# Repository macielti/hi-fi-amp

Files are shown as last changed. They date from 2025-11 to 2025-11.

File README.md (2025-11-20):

# Hi-Fi Audio Amplifier project

Class A audio amplifier project based on JLH 1969 project.

Lista de componentes com valores aproximados: [Lista de Componentes Eletrônicos](https://github.com/macielti/hi-fi-amp/blob/main/docs/Lista%20de%20Componentes%20Eletrônicos.md)

## Exemplo da placa Fonte de Alimentação montada

<p align="center">
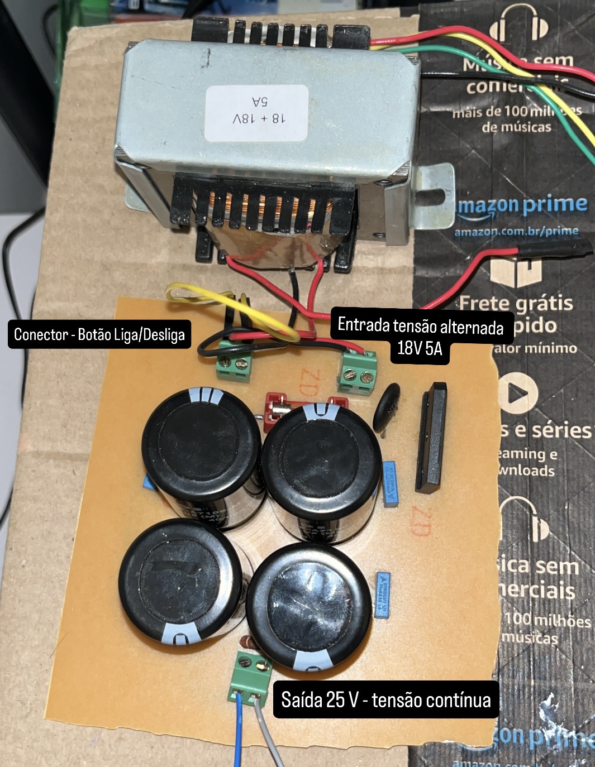
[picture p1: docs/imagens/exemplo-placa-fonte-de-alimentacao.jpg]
  
</p>

## Exemplo da placa Amplificadora de Áudio montada

<p align="center">
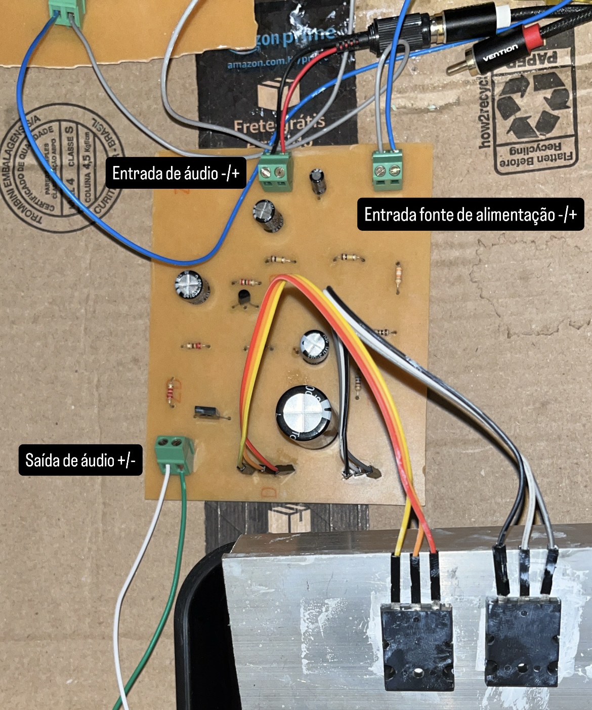
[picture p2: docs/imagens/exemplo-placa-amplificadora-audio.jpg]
  
</p>

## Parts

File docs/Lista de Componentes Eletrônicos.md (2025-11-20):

# Lista de Componentes Eletrônicos

## Fonte de Alimentação 

- 1x NTC 10D-15R                              (unidade ≈ R$ 3,34)
- 4x Capacitor Eletrolítico 10000mf 63V       (R$ 42,22)
- 1x Placa Fenolite 15X15 Face Simples        (R$ 10,50)
- 4x Capacitor Poliéster 100K 63V             (R$ 0,55)
- 3x Borne KRE 2 Terminais 45 Graus           (R$ 2,34)
- 1x Diodo Ponte GBL-2510                     (R$ 12,23)
- 1x Fusível de Vidro 5A                      (R$ 0,45)
- 1x Porta Fusível                            (R$ 5,00)
- 1x Chave Redonda Liga/Desliga 10A           (R$ 3,33)
- 1x Transformador 18v+18v 5a (trafo) Bivolt  (R$ 90,25)

Valor total aproximado (somente a Fonte de Alimentação): **≈ R$ 303,20**

## Amplificador de Áudio

- 1x Placa Fenolite 15X15 Face Simples  (unidade ≈ R$ 10,50)

### Resistores (todos 1/4 W)

- 1x 100Ω   (unidade ≈ R$ 0,18)
- 1x 560Ω   (R$ 0,18)
- 1x 2.7kΩ  (R$ 0,18)
- 1x 220Ω   (R$ 0,18)
- 1x 2.2kΩ  (R$ 0,18)
- 1x 2kΩ    (R$ 0,18)
- 1x 39kΩ   (R$ 0,18)
- 2x 100kΩ  (R$ 0,18)

### Capacitores (todos eletrolíticos e 35V ou mais)

- 2x 330mf  (unidade ≈ R$ 1,55)
- 1x 100mf  (R$ 1,12)
- 1x 10mf   (R$ 0,37)
- 1x 4700mf (R$ 6,00)

### Transistores

- 2x 2SC5200 (unidade ≈ R$ 28,00)
- 1x BC556   (R$ 0,44)
- 1x MJE340  (R$ 2,00)

Valor total aproximado (somente Amplificador de Áudio): **≈ R$ 81,15**

## Valor total do projeto (versão mono): ≈ R$ 384,35

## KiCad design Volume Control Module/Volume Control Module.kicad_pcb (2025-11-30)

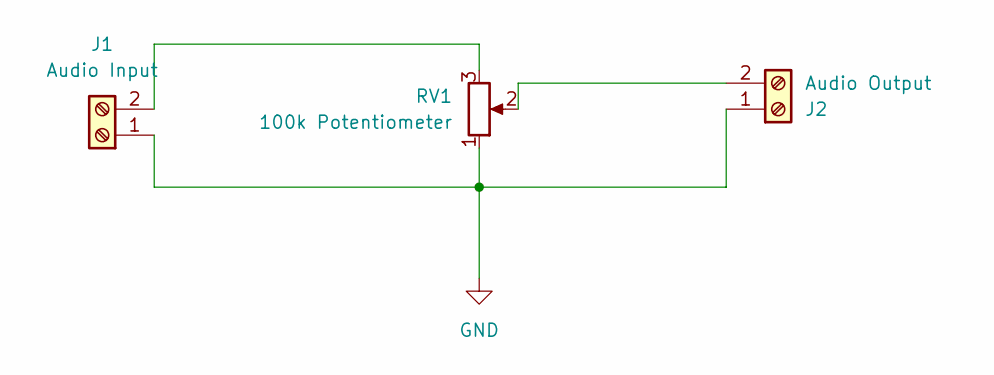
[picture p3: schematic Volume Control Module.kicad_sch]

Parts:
J1: Audio Input; TerminalBlock_MaiXu_MX126-5.0-02P_1x02_P5.00mm
J2: Audio Output; TerminalBlock_MaiXu_MX126-5.0-02P_1x02_P5.00mm
RV1: 100k Potentiometer; Potentiometer_Alps_RK163_Single_Horizontal

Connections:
GND: J1.1, J2.1, RV1.1
unnamed: J1.2, RV1.3
unnamed: J2.2, RV1.2

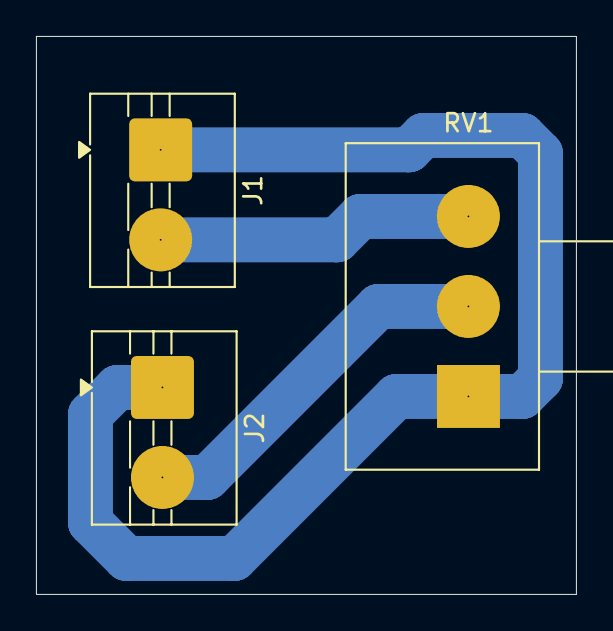
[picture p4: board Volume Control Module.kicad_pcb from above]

Board: 2 copper layers, 30.0 x 31.0 mm, 3 parts (0 on the bottom side), 3 nets.

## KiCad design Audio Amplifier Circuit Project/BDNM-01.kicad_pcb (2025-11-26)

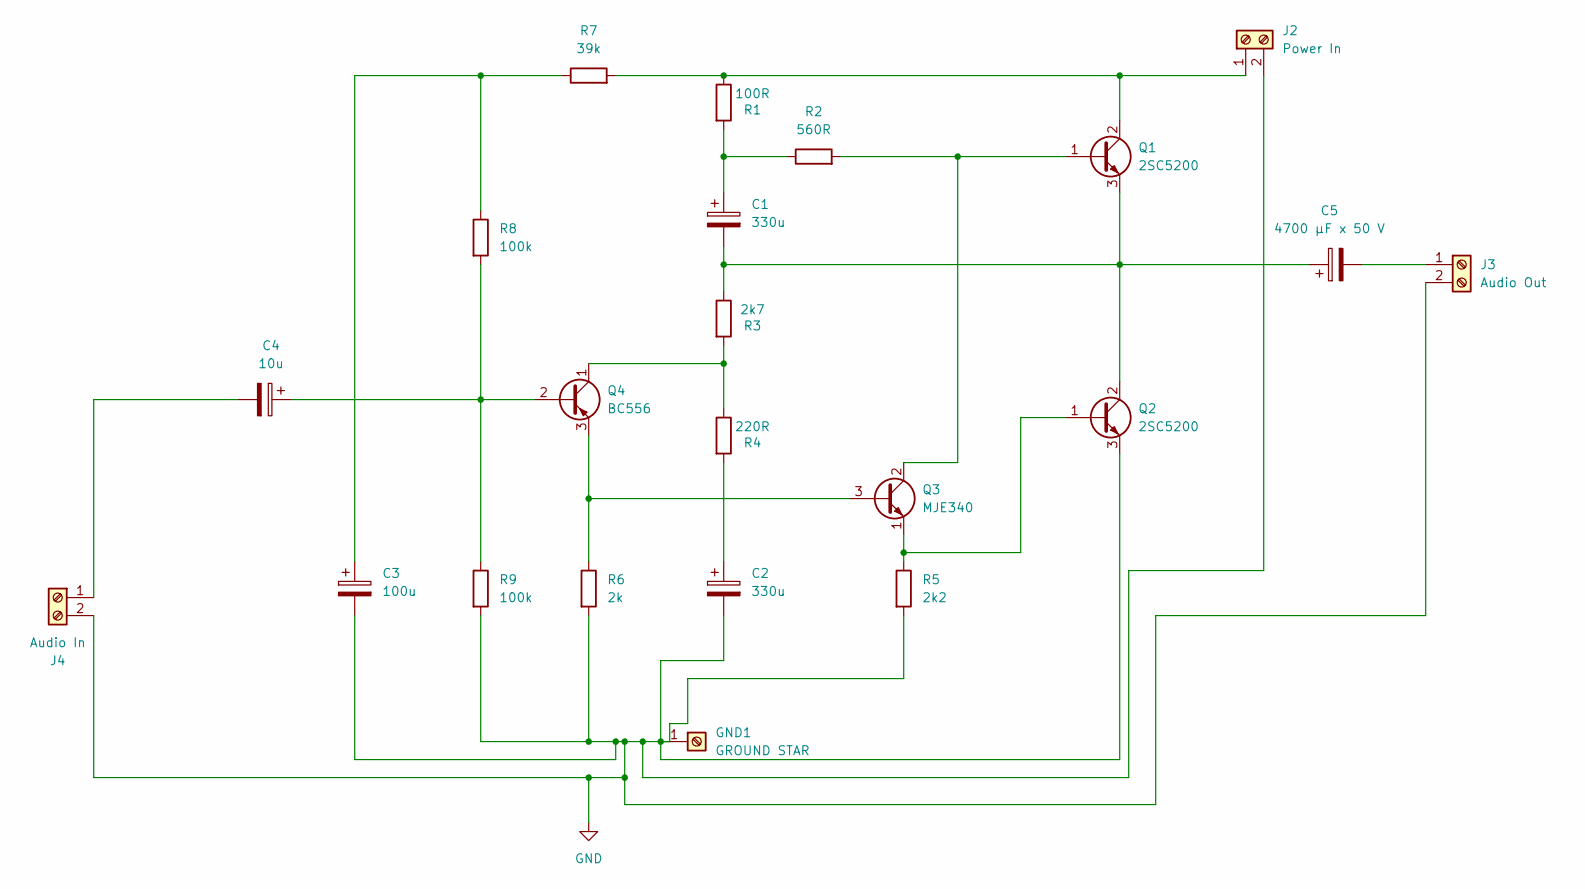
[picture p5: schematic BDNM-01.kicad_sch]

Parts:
C1, C2: 330u; CP_Radial_D10.0mm_P5.00mm
C3: 100u; CP_Radial_D6.3mm_P2.50mm
C4: 10u; CP_Radial_D5.0mm_P2.00mm
C5: 4700 µF x 50 V; CP_Radial_D22.0mm_P10.00mm_SnapIn
GND1: GROUND STAR; TestPoint_THTPad_D4.0mm_Drill2.0mm
J2: Power In; Altech_AK300_1x02_P5.00mm_45-Degree
J3: Audio Out; Altech_AK300_1x02_P5.00mm_45-Degree
J4: Audio In; Altech_AK300_1x02_P5.00mm_45-Degree
Q1, Q2: 2SC5200; TO-264-3_Vertical
Q3: MJE340; TO-220-3_Vertical
Q4: BC556; TO-92_Inline
R1: 100R; R_Axial_DIN0207_L6.3mm_D2.5mm_P10.16mm_Horizontal
R2: 560R; R_Axial_DIN0207_L6.3mm_D2.5mm_P10.16mm_Horizontal
R3: 2k7; R_Axial_DIN0207_L6.3mm_D2.5mm_P10.16mm_Horizontal
R4: 220R; R_Axial_DIN0207_L6.3mm_D2.5mm_P10.16mm_Horizontal
R5: 2k2; R_Axial_DIN0207_L6.3mm_D2.5mm_P10.16mm_Horizontal
R6: 2k; R_Axial_DIN0207_L6.3mm_D2.5mm_P10.16mm_Horizontal
R7: 39k; R_Axial_DIN0207_L6.3mm_D2.5mm_P10.16mm_Horizontal
R8, R9: 100k; R_Axial_DIN0207_L6.3mm_D2.5mm_P10.16mm_Horizontal

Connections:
GND: C2.2, C3.2, GND1.1, J2.2, J3.2, J4.2, Q2.3 (E), R5.2, R6.2, R9.2
unnamed: C1.1, R1.2, R2.1
unnamed: C2.1, R4.2
unnamed: C3.1, R7.1, R8.1
unnamed: J2.1, Q1.2 (C), R1.1, R7.2
unnamed: C5.2, J3.1
unnamed: C4.2, J4.1
unnamed: Q1.1 (B), Q3.2 (C), R2.2
unnamed: C1.2, C5.1, Q1.3 (E), Q2.2 (C), R3.1
unnamed: Q2.1 (B), Q3.1 (E), R5.1
unnamed: Q3.3 (B), Q4.3 (E), R6.1
unnamed: C4.1, Q4.2 (B), R8.2, R9.1
unnamed: Q4.1 (C), R3.2, R4.1

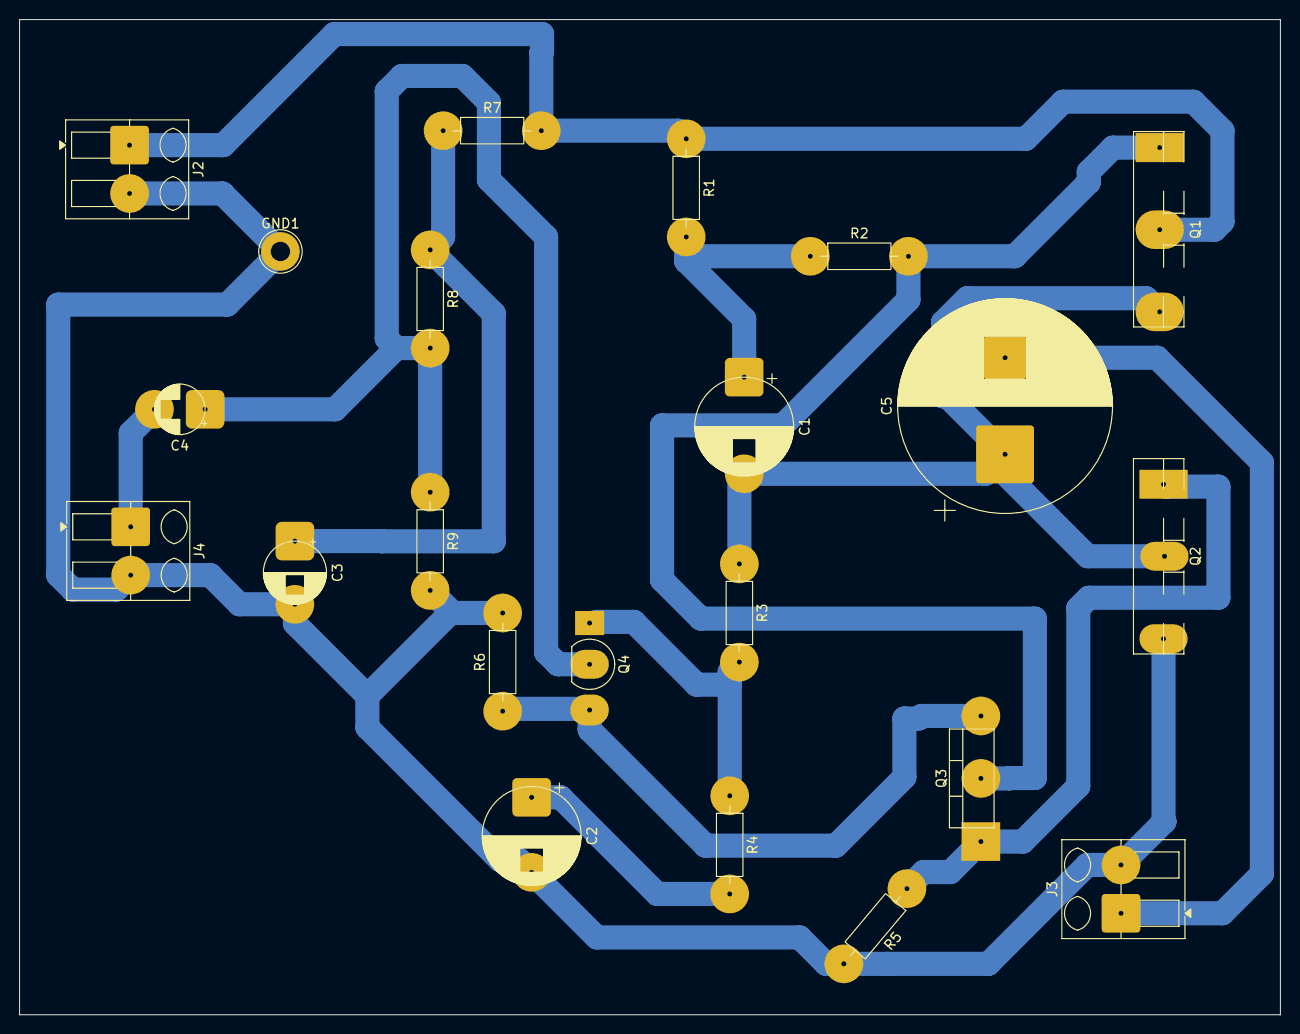
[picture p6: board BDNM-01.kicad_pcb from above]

Board: 2 copper layers, 130.5 x 103.0 mm, 22 parts (0 on the bottom side), 13 nets.

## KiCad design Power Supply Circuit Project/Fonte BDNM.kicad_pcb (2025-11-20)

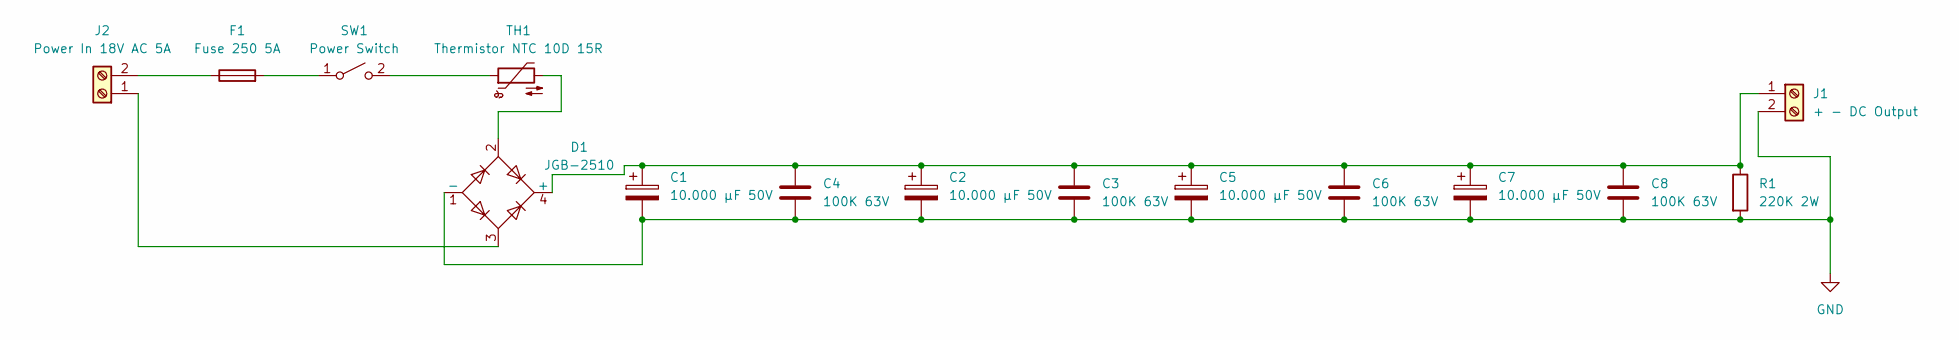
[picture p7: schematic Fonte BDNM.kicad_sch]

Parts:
C1, C2, C5, C7: 10.000 µF 50V; CP_Radial_D25.0mm_P10.00mm_SnapIn
C3, C4, C6, C8: 100K 63V; C_Rect_L7.2mm_W3.5mm_P5.00mm_FKS2_FKP2_MKS2_MKP2
D1: JGB-2510; Diode_Bridge_32.0x5.6x17.0mm_P10.0mm_P7.5mm
F1: Fuse 250 5A; Fuseholder_Cylinder-6.3x32mm_Schurter_0031-8002_Horizontal_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
J1: + - DC Output; TerminalBlock_MaiXu_MX126-5.0-02P_1x02_P5.00mm
J2: Power In 18V AC 5A; TerminalBlock_MaiXu_MX126-5.0-02P_1x02_P5.00mm
R1: 220K 2W; R_Axial_DIN0207_L6.3mm_D2.5mm_P7.62mm_Horizontal
SW1: Power Switch; TerminalBlock_MaiXu_MX126-5.0-02P_1x02_P5.00mm
TH1: Thermistor NTC 10D 15R; RV_Disc_D21.5mm_W6.1mm_P7.5mm

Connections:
GND: C1.2, C2.2, C3.2, C4.2, C5.2, C6.2, C7.2, C8.2, D1.1 (-), J1.2, R1.2
unnamed: C1.1, C2.1, C3.1, C4.1, C5.1, C6.1, C7.1, C8.1, D1.4 (+), J1.1, R1.1
unnamed: D1.2, TH1.2
unnamed: D1.3, J2.1
unnamed: F1.1, J2.2
unnamed: F1.2, SW1.1 (A)
unnamed: SW1.2 (B), TH1.1

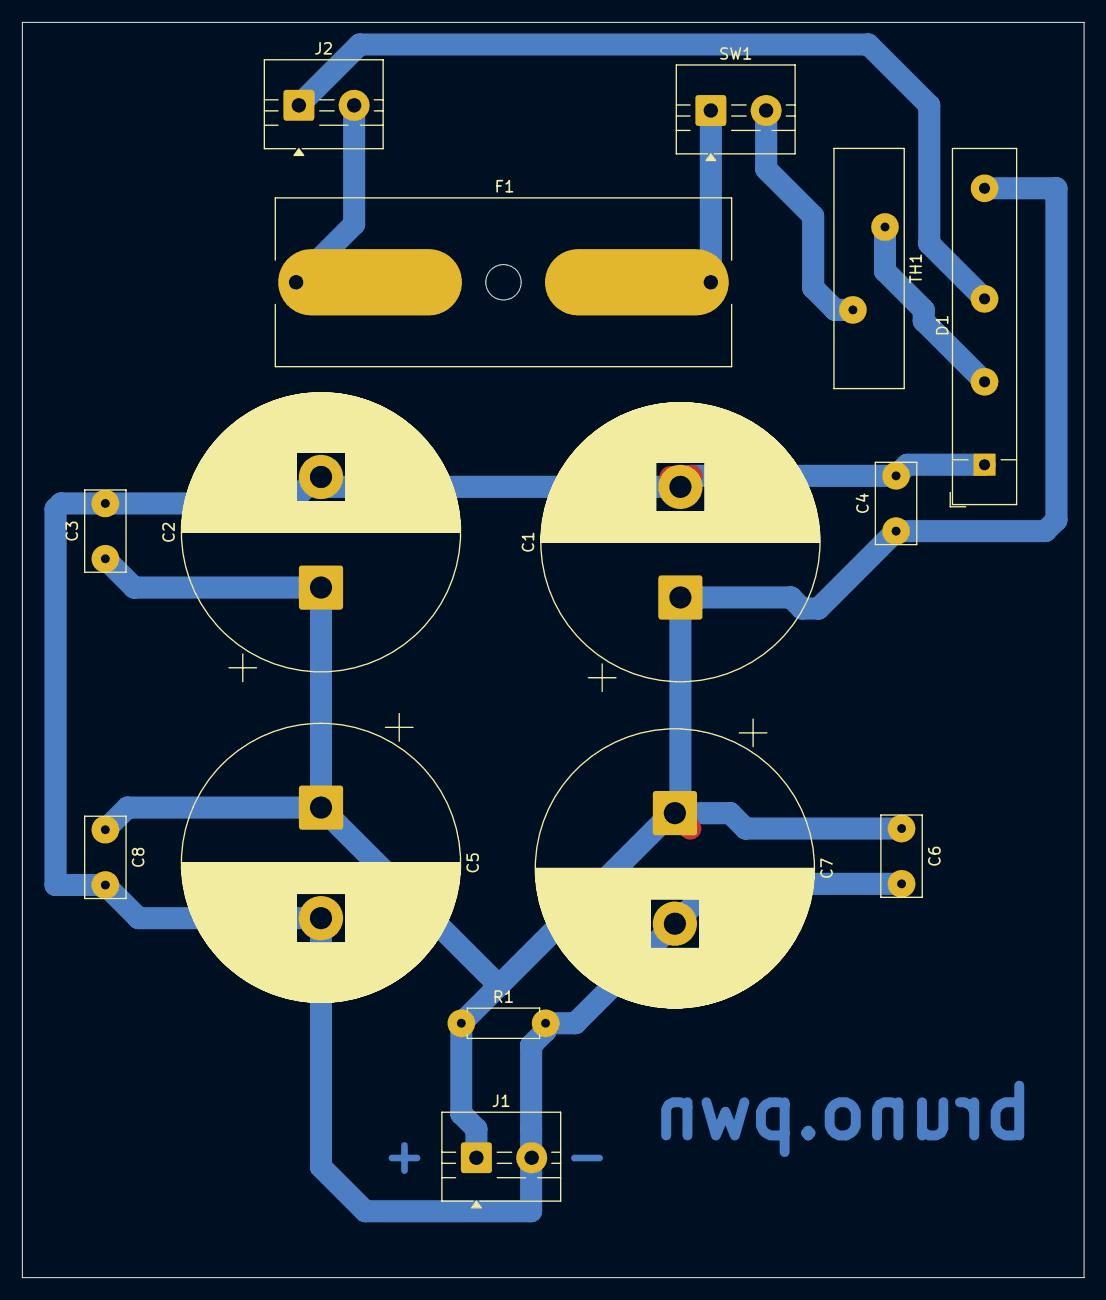
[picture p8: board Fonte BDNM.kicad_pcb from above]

Board: 2 copper layers, 96.0 x 113.5 mm, 15 parts (0 on the bottom side), 7 nets.

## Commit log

2025-11-20 add files for milling
    [Fonte BDNM.kicad_pcb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]
2025-11-20 milling deeper
2025-11-26 gcode for audio amp board
    [BDNM-01.kicad_pcb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]
2025-11-30 add volume control module
    [Volume Control Module.kicad_pcb, Volume Control Module.kicad_sch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]
2025-11-30 drill more deep
